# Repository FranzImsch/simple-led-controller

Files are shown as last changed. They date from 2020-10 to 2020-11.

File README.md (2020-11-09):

# Simplest LED Controller

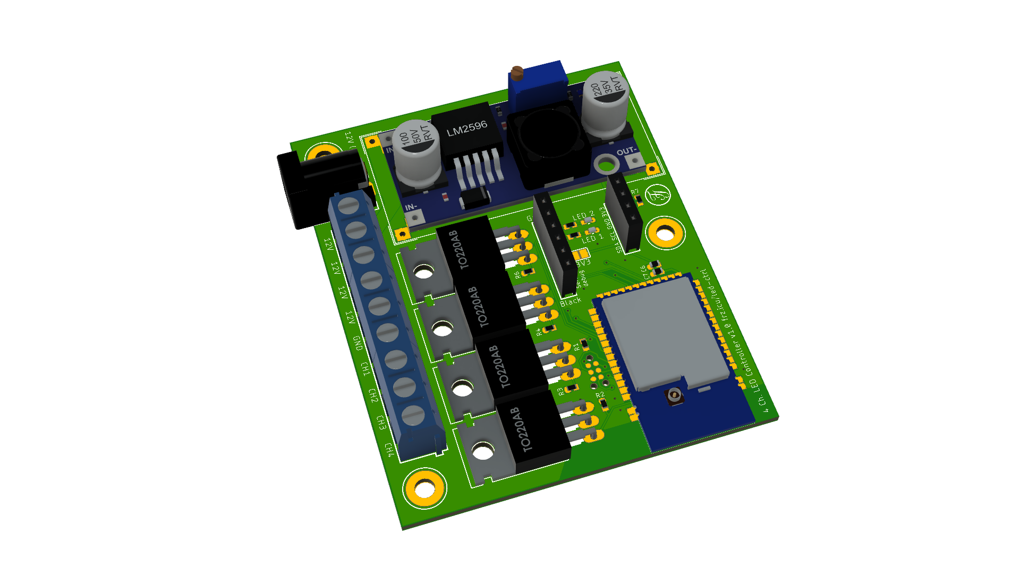
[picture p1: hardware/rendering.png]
rendering


# Abstract
As home automation becomes more and more popular, more and more smart home enabled devices replace old-fashioned switch-controlled devices. However, different systems have several advantages and disadvantages that makes it hard to choose the perfect system. A solution to that is to make your own smart home devices.  
This project’s goal was to minimise both the complexity and the cost of such a self-built device. 

# Features
The “Simplest-LED-Controller” features 3 usable PWM-controlled channels (and one on-off channel) and is being programmed using the Arduino framework. It consists of very basic components with the exception of the nRF52-module. The latter is the MCU of the project and it communicates via ESB-protocol with a gateway. This module consumes very little energy while idling, making it a much better solution than WiFi-based ones.

# Hardware
The LEDs are controlled using 4 Mosfets (IRLZ44N) that are broadly available. The power for the MCU is supplied by a LM2596-Module that can be purchased very cheaply. For basic functionality, only the nRF-module, the buck converter, the Mosfets, the screw terminals and a few 0603 10k resistors are necessary.  
```Note: always adjust the step down converter's voltage to 3.3V before assembling!```  
The board also features an interface for a FTDI (or equivalent) and a breakout of the I2C pins, so a sensor could be connected to the MCU in addition.  
The board is being programmed through a Tag-Connect interface using a J-Link or similar.

# Software
As for the software, the MySensors library is used to allow an easy implementation of the ESB-protocol of the nRF52.

## Partlist

|Component           |Value                    | Package |
|--------------------|-------------------------|---------|
|C6                  | 10µF Cap                |0603     |
|C7                  | 0.1µF Cap               |0603     |
|D2, D3              | LED                     |0603     |
|IC3                 | E73_2G4M04S             |         |
|J1                  | Socket Header 6P        |         |
|J2                  | Socket Header 4P        |         |
|J4                  | Screw Terminal (3*3P)   |         |
|Q1-Q4               | IRLZ44N                 ||TO-220  |
|R1-R4, R6           | 10K Resistor            |0603     |
|R5, R17             | 1K Resistor             |0603     |
|R7, R8              | I2C Pullups             |0603     |
|U$1                 | LM2596-MODULE           |         |

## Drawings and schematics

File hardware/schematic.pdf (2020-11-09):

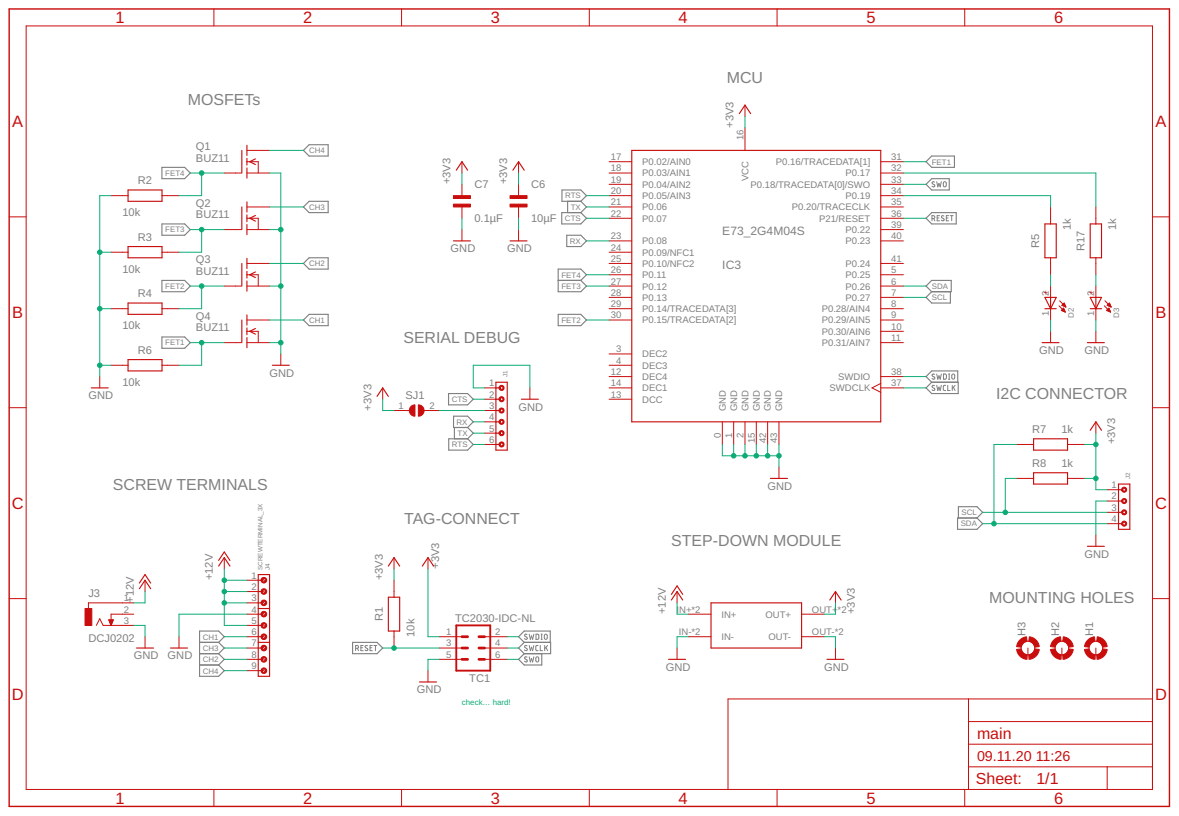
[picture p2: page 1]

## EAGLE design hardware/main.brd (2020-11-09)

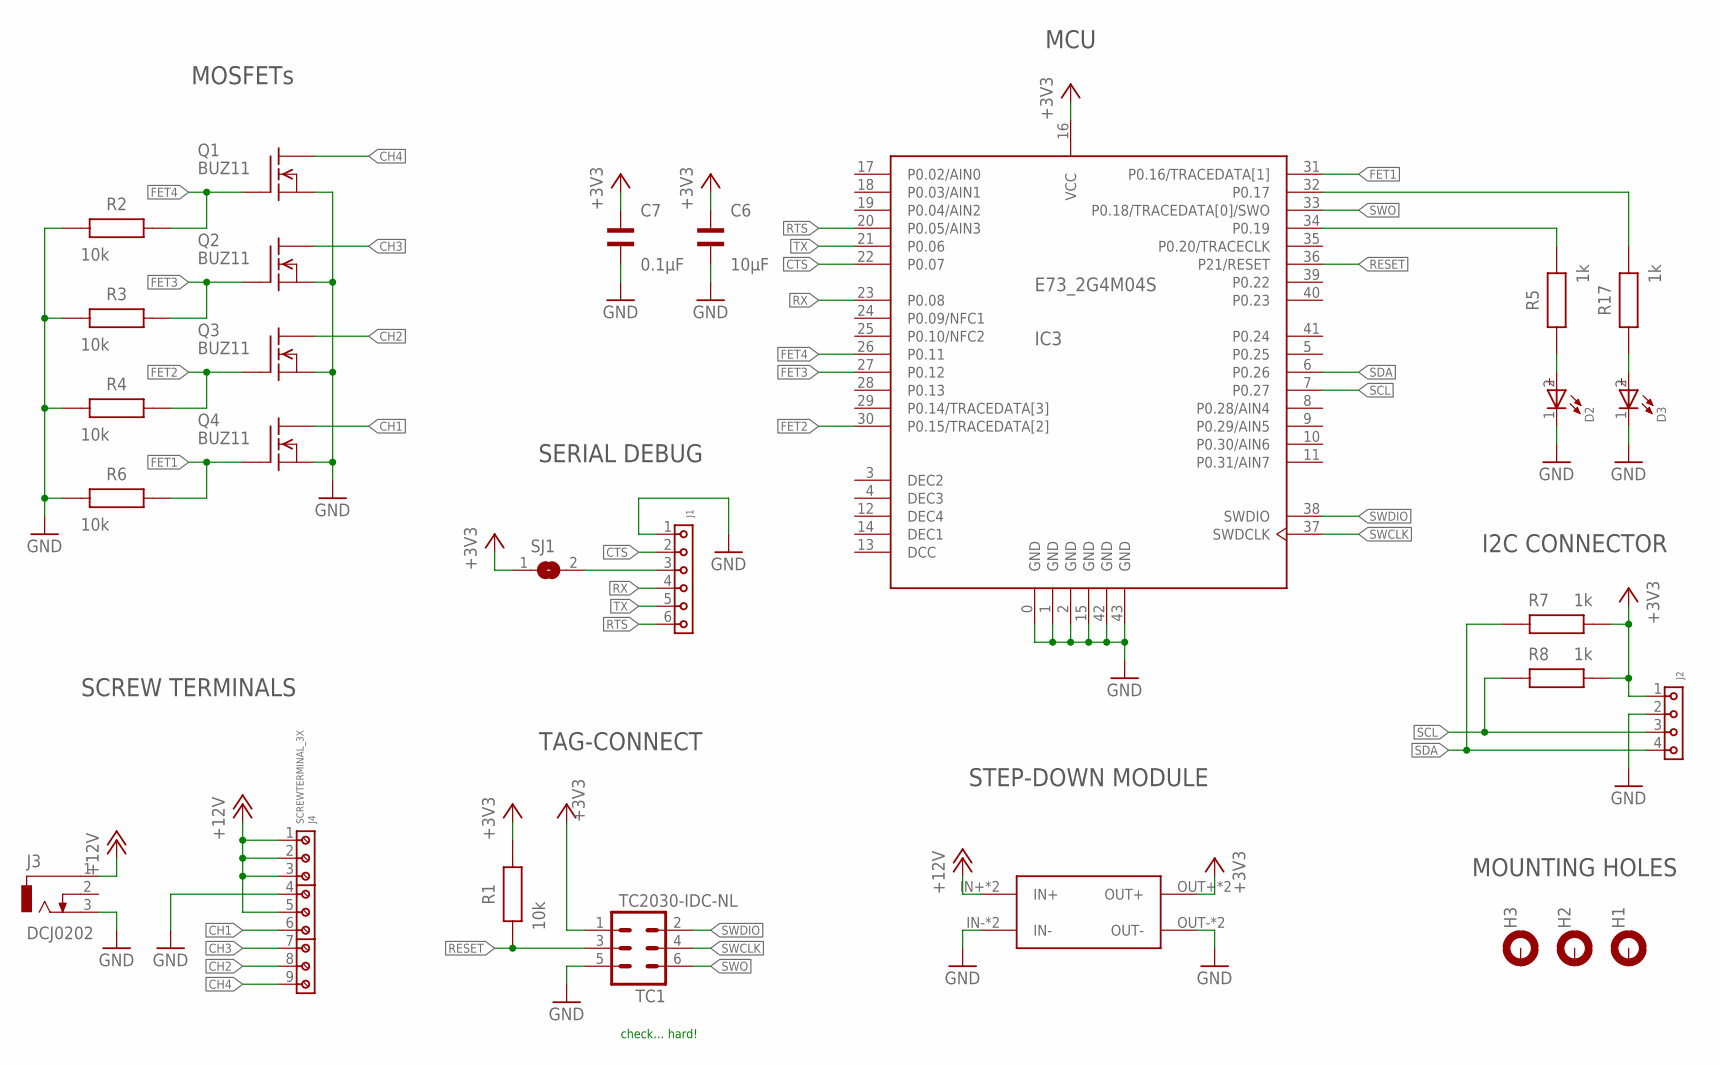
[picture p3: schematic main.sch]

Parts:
C6: 10µF; WCAP-CSGP_0603_REFLOW
C7: 0.1µF; WCAP-CSGP_0603_REFLOW
D2, D3: WL-SMCW_0603_150060BS75000; WL-SMCW_0603
H1, H2, H3: MOUNT-PAD-ROUND3.2; 3,2-PAD
IC3: E73_2G4M04S
J1: 6130XX11821_61300611821; 61300611821
J2: 6130XX11821_61300411821; 61300411821
J3: DCJ0202
J4: SCREWTERMINAL_3X; 691102710003
Q1, Q2, Q3, Q4: BUZ11; TO220
R1, R2, R3, R4, R6: 10k; WRIS-PSMB_0603_1.6X0.8X0.35X0.6(LXWXHXPW)
R5, R7, R8, R17: 1k; WRIS-PSMB_0603_1.6X0.8X0.35X0.6(LXWXHXPW)
SJ1: SJ
TC1: TC2030-IDC-NL
U$1: LM2596-MODULE

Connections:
+3V3: C6.2, C7.2, IC3.16 (VCC), J2.1, R1.2, R7.1, R8.1, SJ1.1, TC1.1, U$1.OUT+, U$1.OUT+1 (OUT+)
+12V: J3.1, J4.1, J4.2, J4.3, J4.5, U$1.IN+, U$1.IN+1 (IN+)
CH1: J4.6, Q4.2 (D)
CH2: J4.8, Q3.2 (D)
CH3: J4.7, Q2.2 (D)
CH4: J4.9, Q1.2 (D)
CTS: IC3.22 (P0.07), J1.2
DCC: IC3.13 (DCC)
DEC1: IC3.14 (DEC1)
DEC2: IC3.3 (DEC2)
DEC3: IC3.4 (DEC3)
DEC4: IC3.12 (DEC4)
FET1: IC3.31 (P0.16/TRACEDATA[1]), Q4.1 (G), R6.2
FET2: IC3.30 (P0.15/TRACEDATA[2]), Q3.1 (G), R4.2
FET3: IC3.27 (P0.12), Q2.1 (G), R3.2
FET4: IC3.26 (P0.11), Q1.1 (G), R2.2
GND: C6.1, C7.1, D2.1 (-), D3.1 (-), IC3.0 (GND), IC3.1 (GND), IC3.2 (GND), IC3.15 (GND), IC3.42 (GND), IC3.43 (GND), J1.1, J2.2, J3.3, J4.4, Q1.3 (S), Q2.3 (S), Q3.3 (S), Q4.3 (S), R2.1, R3.1, R4.1, R6.1, TC1.5, U$1.IN-, U$1.IN-1 (IN-), U$1.OUT-, U$1.OUT-1 (OUT-)
unnamed: J1.3, SJ1.2
unnamed: D2.2 (+), R5.2
unnamed: D3.2 (+), R17.2
unnamed: IC3.32 (P0.17), R17.1
unnamed: IC3.34 (P0.19), R5.1
RESET: IC3.36 (P21/RESET), R1.1, TC1.3
RTS: IC3.20 (P0.05/AIN3), J1.6
RX: IC3.23 (P0.08), J1.4
SCL: IC3.7 (P0.27), J2.3, R8.2
SDA: IC3.6 (P0.26), J2.4, R7.2
SWCLK: IC3.37 (SWDCLK), TC1.4
SWDIO: IC3.38 (SWDIO), TC1.2
SWO: IC3.33 (P0.18/TRACEDATA[0]/SWO), TC1.6
TX: IC3.21 (P0.06), J1.5

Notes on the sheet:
check… hard!
MCU
MOSFETs
SCREW TERMINALS
STEP-DOWN MODULE
TAG-CONNECT
MOUNTING HOLES
SERIAL DEBUG
I2C CONNECTOR

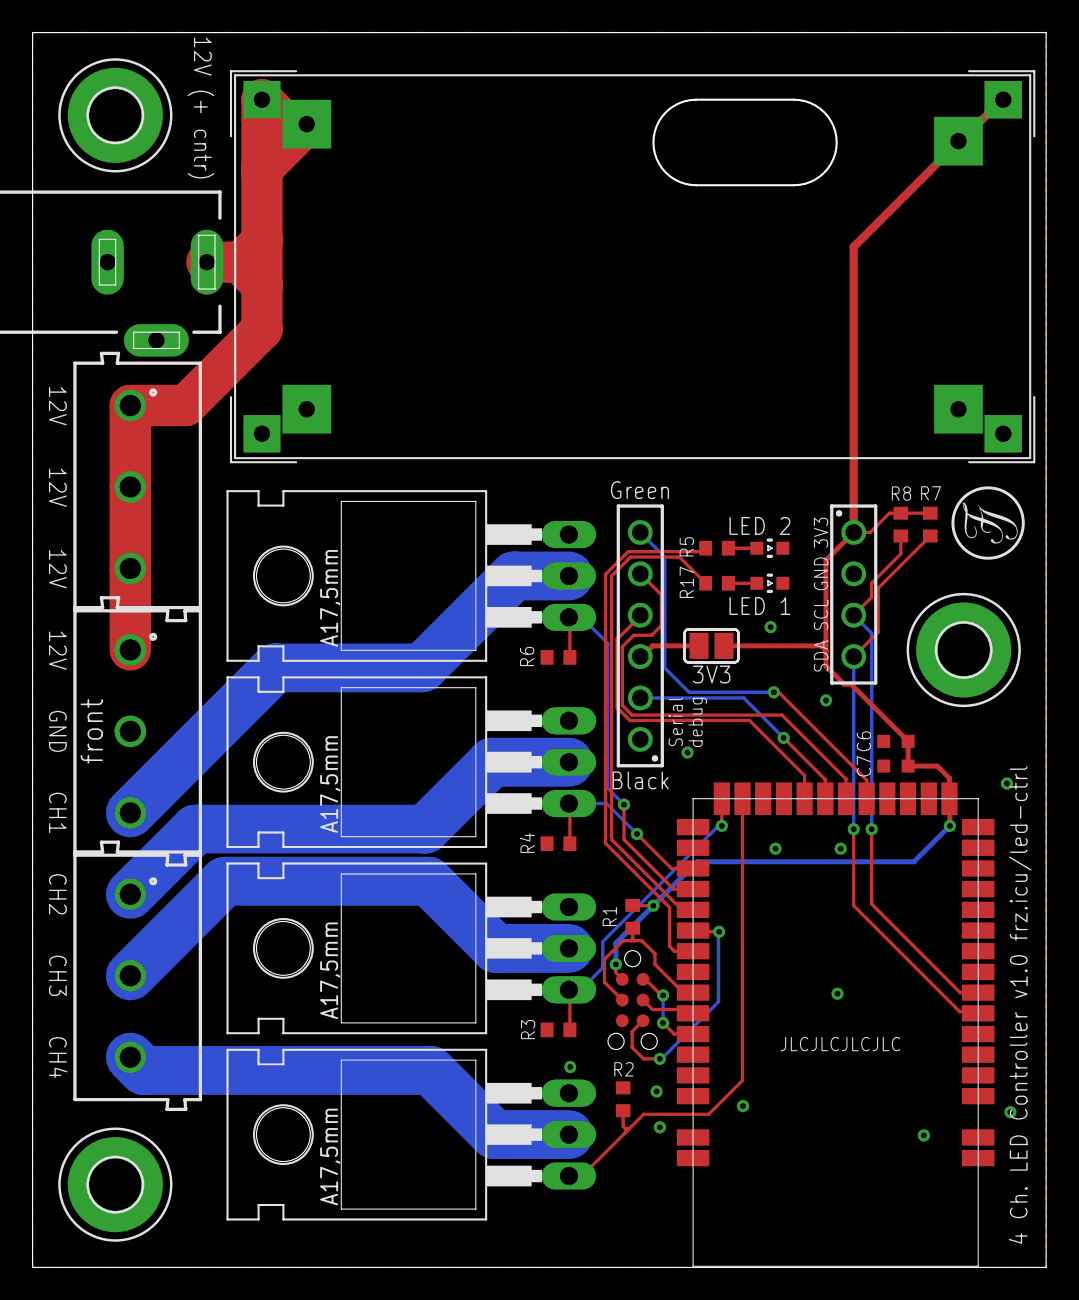
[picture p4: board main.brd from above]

Board: 2 copper layers, 62.2 x 75.8 mm, 28 parts (0 on the bottom side), 26 nets.

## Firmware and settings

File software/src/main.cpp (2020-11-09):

#include <Arduino.h>

// Code made for "Simplest LED Controller" https://frz.icu/led-ctrl

// nRF52 Arduino implementation does not support multiple pins for
// one PWM unit, so a maximum of 3 channels can be controlled at a
// time with this sketch.
//
// One possible solution to this would be to use one channel as a
// digital output only (meaning just on or off capability).

// ************* User Configuration ************* //

// #define MY_DEBUG

#define MY_RADIO_NRF5_ESB
// #define MY_REPEATER_FEATURE

#define SN "Simplest-LED-Controller"
#define SV "1.0"

#define numChannels 4 // Select amount of populated mosfets.

#define blinkLED // Makes the on board LED blink whenever a command is received

#define gammaCorrection

// ********************************************** //

const byte CHILD_ID[5] = {0, 1, 2, 3, 4};

#define LIGHT_OFF 0
#define LIGHT_ON 1

#include <MySensors.h>

// Sketch is made for a max. of 4 channels. Index 0 is not used
// to assign index 1 to ch1 …
int16_t last_state[5] = {0, LIGHT_ON, LIGHT_ON, LIGHT_ON, LIGHT_ON};
int16_t last_dim[5] = {0, 0, 0, 0, 0};

MyMessage light_msg[5] = {MyMessage(), MyMessage(CHILD_ID[1], V_STATUS), MyMessage(CHILD_ID[2], V_STATUS), MyMessage(CHILD_ID[3], V_STATUS), MyMessage(CHILD_ID[4], V_STATUS)};
MyMessage dimmer_msg[5] = {MyMessage(), MyMessage(CHILD_ID[1], V_PERCENTAGE), MyMessage(CHILD_ID[2], V_PERCENTAGE), MyMessage(CHILD_ID[3], V_PERCENTAGE), MyMessage(CHILD_ID[4], V_PERCENTAGE)};

const byte channelToPin[5] = {0, 5, 4, 1, 0}; // Assigning Ch 1 to pin 5, ...
const byte LED_ONBOARD[3] = {0, 6, 8};
#ifdef gammaCorrection
extern const uint8_t gamma8[];
#endif

void presentation()
{
  // Send the sketch version information to the gateway
  sendSketchInfo(SN, SV);

  for (byte a = 1; a <= numChannels; a++)
  {
    present(CHILD_ID[a], S_DIMMER);
    wait(5);
  }
}

void update_light()
{
  for (byte b = 1; b <= numChannels; b++)
  {
    if (last_state[b] == LIGHT_OFF)
    {
      Serial.println("Light state: OFF");
      analogWrite(channelToPin[b], 0);
    }
    else
    {
      Serial.print("Light state: ON, Level: ");
      Serial.println(last_dim[b]);
#ifdef gammaCorrection
      int value = (last_dim[b]/100.00)*255.00;
      analogWrite(channelToPin[b], pgm_read_byte(&gamma8[value]));
#else
      analogWrite(channelToPin[b], (last_dim[b] / 100.00) * 255.00);
#endif
    }
  }
}

void blinkOnboardLED(byte LED, bool makeOn)
{
#ifdef blinkLED
  if (makeOn)
  {
    digitalWrite(LED_ONBOARD[LED], HIGH);
  }
  else if (!makeOn)
  {
    digitalWrite(LED_ONBOARD[LED], LOW);
  }
#endif
}

void send_dimmer_message()
{
  blinkOnboardLED(2, true);
  for (byte c = 1; c <= numChannels; c++)
  {
    send(dimmer_msg[c].set(last_dim[c]));
    delay(50);
  }
  blinkOnboardLED(2, false);
}

void send_status_message()
{
  blinkOnboardLED(2, true);
  for (byte d = 1; d <= numChannels; d++)
  {
    if (last_state[d] == LIGHT_OFF)
    {
      send(light_msg[d].set((int16_t)0));
    }
    else
    {
      send(light_msg[d].set((int16_t)1));
    }
  }
  blinkOnboardLED(2, false);
}

void receive(const MyMessage &message)
{
  blinkOnboardLED(1, true);
  //When receiving a V_STATUS command, switch the light between OFF
  //and the last received dimmer value
  if (message.type == V_STATUS)
  {
    Serial.println("V_STATUS command received...");

    int lstate = message.getInt();

    if ((lstate < 0) || (lstate > 1))
    {
      Serial.println("V_STATUS data invalid (should be 0/1)");
      return;
    }

    byte e = message.sensor;
    last_state[e] = lstate;

    if ((last_state[e] == LIGHT_ON) && (last_dim[e] == 0))
    {
      last_dim[e] = 100;
    }

    //Update constroller status
    send_status_message();
  }
  else if (message.type == V_PERCENTAGE)
  {
    Serial.println("V_PERCENTAGE command received...");
    int dim_value = constrain(message.getInt(), 0, 100);
    if (dim_value == 0)
    {
      byte e = message.sensor;
      last_state[e] = LIGHT_OFF;

      //Update constroller with dimmer value & status
      send_dimmer_message();
      send_status_message();
    }
    else
    {
      byte e = message.sensor;
      last_state[e] = LIGHT_ON;
      last_dim[e] = dim_value;

      //Update constroller with dimmer value
      send_dimmer_message();
    }
  }
  else
  {
    Serial.println("Invalid command received...");
    return;
  }

  blinkOnboardLED(1, false);

  //Here you set the actual light state/level
  update_light();
}

void setup()
{
  Serial.begin(115200);
  pinMode(LED_ONBOARD[1], OUTPUT);
  pinMode(LED_ONBOARD[2], OUTPUT);
  delay(1000);
  update_light();
  Serial.println("Node ready to receive messages...");
}

void loop()
{
  //In MySensors2.x, first message must come from within loop()
  static bool first_message_sent = false;
  if (first_message_sent == false)
  {
    Serial.println("Sending initial state...");
    send_dimmer_message();
    send_status_message();
    first_message_sent = true;
  }
}

#ifdef gammaCorrection
const uint8_t PROGMEM gamma8[] = {
0, 0, 0, 0, 0, 0, 0, 0, 0, 0, 0, 0, 0, 0, 0, 0,
0, 0, 0, 0, 0, 0, 0, 0, 0, 0, 0, 0, 1, 1, 1, 1,
1, 1, 1, 1, 1, 1, 1, 1, 1, 2, 2, 2, 2, 2, 2, 2,
2, 3, 3, 3, 3, 3, 3, 3, 4, 4, 4, 4, 4, 5, 5, 5,
5, 6, 6, 6, 6, 7, 7, 7, 7, 8, 8, 8, 9, 9, 9, 10,
10, 10, 11, 11, 11, 12, 12, 13, 13, 13, 14, 14, 15, 15, 16, 16,
17, 17, 18, 18, 19, 19, 20, 20, 21, 21, 22, 22, 23, 24, 24, 25,
25, 26, 27, 27, 28, 29, 29, 30, 31, 32, 32, 33, 34, 35, 35, 36,
37, 38, 39, 39, 40, 41, 42, 43, 44, 45, 46, 47, 48, 49, 50, 50,
51, 52, 54, 55, 56, 57, 58, 59, 60, 61, 62, 63, 64, 66, 67, 68,
69, 70, 72, 73, 74, 75, 77, 78, 79, 81, 82, 83, 85, 86, 87, 89,
90, 92, 93, 95, 96, 98, 99,101,102,104,105,107,109,110,112,114,
115,117,119,120,122,124,126,127,129,131,133,135,137,138,140,142,
144,146,148,150,152,154,156,158,160,162,164,167,169,171,173,175,
177,180,182,184,186,189,191,193,196,198,200,203,205,208,210,213,
215,218,220,223,225,228,231,233,236,239,241,244,247,249,252,255 };
#endif

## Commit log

2020-10-19 added dc barrel jack
    [main.brd, main.sch]
2020-11-09 enhanced Readme after testing
    [main.brd, main.sch]

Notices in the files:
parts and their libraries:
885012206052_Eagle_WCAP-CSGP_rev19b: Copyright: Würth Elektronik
